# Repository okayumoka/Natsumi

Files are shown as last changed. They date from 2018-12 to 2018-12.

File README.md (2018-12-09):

# Natsumi

Natsumiは、コンパクトな左右分割型の自作キーボードです。

## 特徴

- 左右分離型
- キー数は両手で52キーと比較的少なく、コンパクト
- 手の形に合わせて山なりに配置したキー配列
- ケーブル類はすべて上部から接続

## 準備物

このリポジトリの内容物に加えて、以下のものが必要です。

### 部品

* ProMicroまたはその互換品×2
* ダイオード（1N4148または1SS178）
* Cherry MXキースイッチ、またはその互換スイッチ
* キーキャップ
* 配線用ケーブル
* [3.5mm 4極ミニジャック 基板取付用 MJ-4PP-9](http://akizukidenshi.com/catalog/g/gC-06070/)（秋月電子で購入可能）
* 3.5mm ステレオミニケーブル
* M3ネジ 長さ8mm ×8本（ケースのフタ固定用）
* M3ネジ 長さ5mm ×2本（ProMicro固定用）

Arduino Microは左右に一つずつ、合計2台必要です。
ダイオード、キースイッチ、キーキャップはキーの数だけ必要です。

### 工具・その他

* 半田ごて、半田
* ヤスリ、カッター（筐体の微調整用）
* グルーガン（ホットボンド）
* 3Dプリンター（なくてもOK）

ケースを印刷するために3Dプリンターを利用しますが、
無い場合は[DMM.make](https://make.dmm.com/print/)などの3Dプリントサービスを利用したので問題ありません。
むしろ多くの場合は、3Dプリントサービスに発注したほうが精度の高いケースを入手できます。

### 入手先

部品、工具の入手先の一例です。

* [TALP KEYBOARD](https://talpkeyboard.stores.jp/)
  * ProMicro互換機、ダイオード、キースイッチ、キーキャップとすべて揃います。
  * AliExpressと比べるとさすがに高いですが、すぐ発送してくれる・国内配送なので安心感があります。
* [AliExpress](https://www.aliexpress.com/)
  * ダイオード以外をAliExpressで買うと一番安く収まると思います。
* [秋月電子](http://akizukidenshi.com/catalog/default.aspx)
  * ダイオード、半田付けの道具、配線用ケーブルなどが購入できます。
  * 3.5mm 4極ミニジャック 基板取付用 MJ-4PP-9 はここで購入できます。
  * 安く揃えるなら以下がおすすめです。
    * 高速スイッチング・ダイオード　１ＳＳ１７８（１００本入）
    * 半田ごて：ニクロムはんだこて　ＫＳ－３０Ｒ（３０Ｗ）
    * 半田：はんだ　０．８ｍｍ SD-62
    * こて台：はんだこて台　ＳＴ－１１
    * ケーブル：スズメッキ線0.6mm、耐熱電子ワイヤー2m×7色
* [Amazon](https://www.amazon.co.jp/)
  * キーキャップ、半田付けの道具などが購入できます。
  * RepRap Prusa i3など、自分で組み立てるタイプの3Dプリンターも比較的安く手に入ります。

### 1.ケースの作成

`case` 以下の3Dモデルがケースとなっています。
3Dプリンターか、3Dプリントサービスを利用して出力します。

自前の3Dプリンターで印刷する場合、素材はPLAがおすすめです。
キーボード筐体は平たく、薄いため、熱収縮の大きいABSで反らないように印刷することは難しいでしょう。

### 2.キースイッチはめ込み

筐体の穴にCherry MXキースイッチをはめ込みます。

3Dプリンターの精度によっては穴のサイズがまちまちなので、ヤスリとカッターで調整します。
削りすぎないように注意してください。

キーキャップを交換するときなどにキースイッチが抜けてしまうのが嫌な場合は、
グルーガンでケースと固定してしまうとよいでしょう。

### 3.ミニジャック固定

3.5mm 4極ミニジャックを筐体に固定します。穴サイズが小さい場合はヤスリで調整します。
固定はグルーガンがおすすめです。

### 4.配線（半田付け）

配線図(`wiring`以下のファイル参照)通りに配線していきます。
ダイオードの向きに注意してください。
キースイッチから伸びている先の数字は、ProMicroのピン番号です。

配線図は、スイッチを筐体にはめ込んで裏返した状態となっています。
表から見た状態ではないので注意してください。

また、ProMicroの互換品はMicro USBジャックが折れやすいものが多いので、グルーガンで補強すると良いでしょう。
ただし、コネクタ内部にグルーガンのボンドが入らないように注意してください。

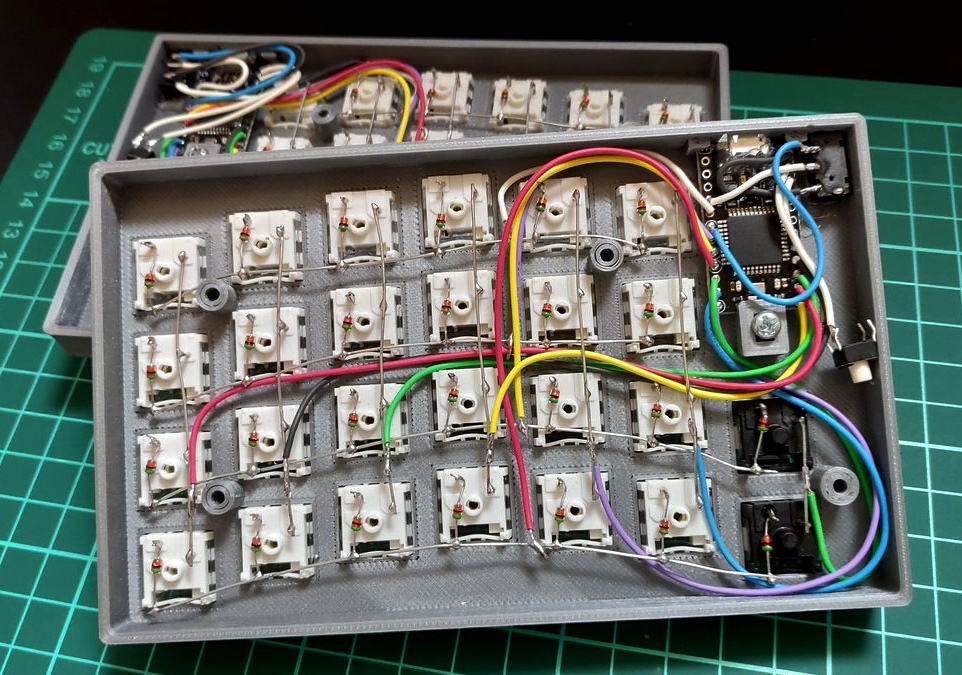
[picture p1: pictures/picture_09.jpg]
配線した状態


### 5.ファームウェア書き込み

ProMicroにQMK Firmwareを書き込みます。
QMK Firmwareのビルド環境を構築した後、`make natsumi:default:avrdude`を実行してください。

(2018/10/14) QMK Firmwareの公式リポジトリにはNatsumi用のファイルが存在していないため、
[こちらのリポジトリ](https://github.com/okayumoka/qmk_firmware)を`git clone`して使用してください。

### 6.ProMicro固定、裏蓋装着

ProMicro固定用の部品とネジで固定します。
グラつくときは、固定用部品をグルーガンで接着してください。

その後、裏蓋をネジ止めします。

### 7.キーキャップはめ込み

お好みのキーキャップを取り付けて、完成です。

## License

MIT License

Copyright (c) 2018 okayu

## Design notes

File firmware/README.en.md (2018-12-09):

# About Firmware

Natsumi work with [QMK Firmware](https://github.com/qmk/qmk_firmware).

# How to build

Setup QMK Firmware, and execute this command.

(2018/10/13) There is no Natsumi's sources in original QMK Firmware repository.
So, please use [this repository](https://github.com/okayumoka/qmk_firmware) files.
QMK Firmwareの公式リポジトリにはNatsumi用のファイルが存在していないため、

```
$ make natsumi:default:avrdude
```

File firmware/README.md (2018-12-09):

# ファームウェアについて

Natsumiは、[QMK Firmware](https://github.com/qmk/qmk_firmware)で動作します。

# ProMicroへの焼き込み手順

QMK Firmwareをビルドできる環境を整えてください。（ネット上にいろんな記事があるはずです。）

2018/10/13 QMK Firmwareの公式リポジトリにはNatsumi用のファイルが存在していないため、
[こちらのリポジトリ](https://github.com/okayumoka/qmk_firmware)を`git clone`して使用してください。

QMK Firmwareのディレクトリで、次のコマンドを実行してください。

```
$ make natsumi:default:avrdude
```

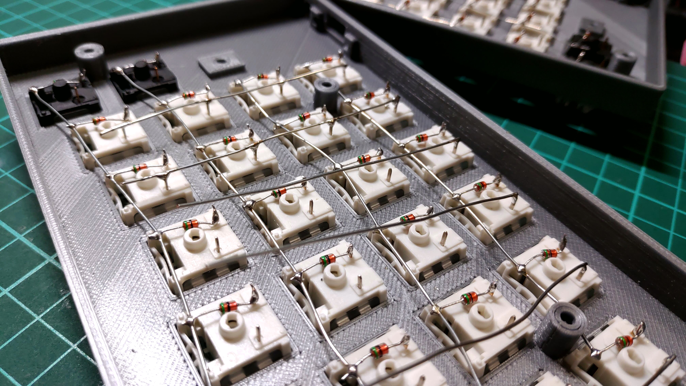
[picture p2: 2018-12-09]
pictures/picture_07.jpg

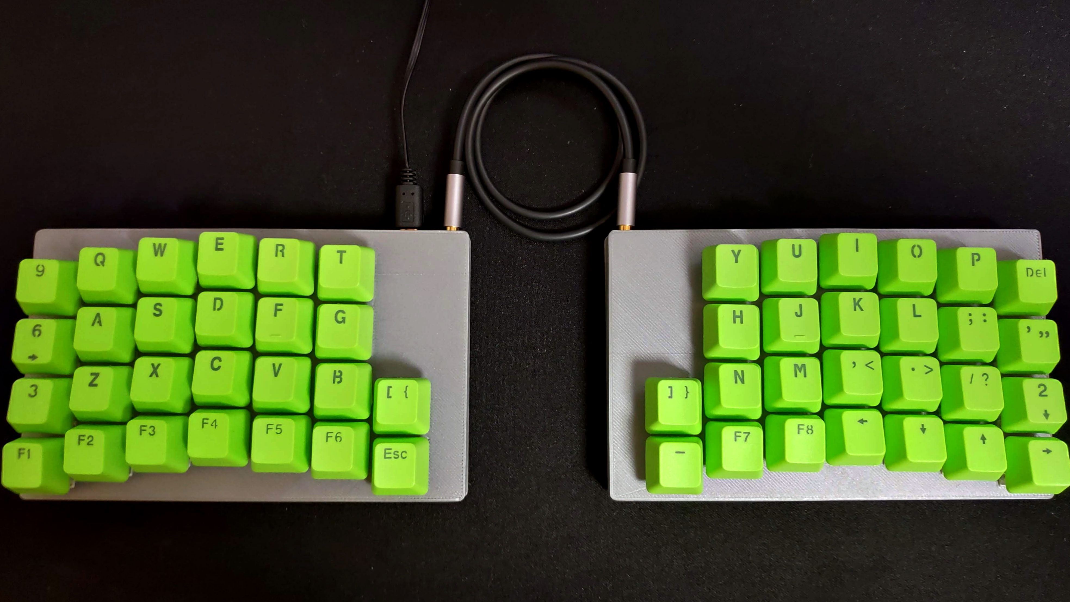
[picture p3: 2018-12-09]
pictures/picture_01.jpg

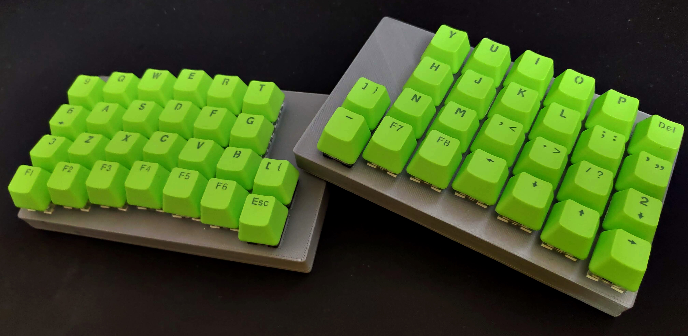
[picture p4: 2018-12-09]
pictures/picture_02.jpg

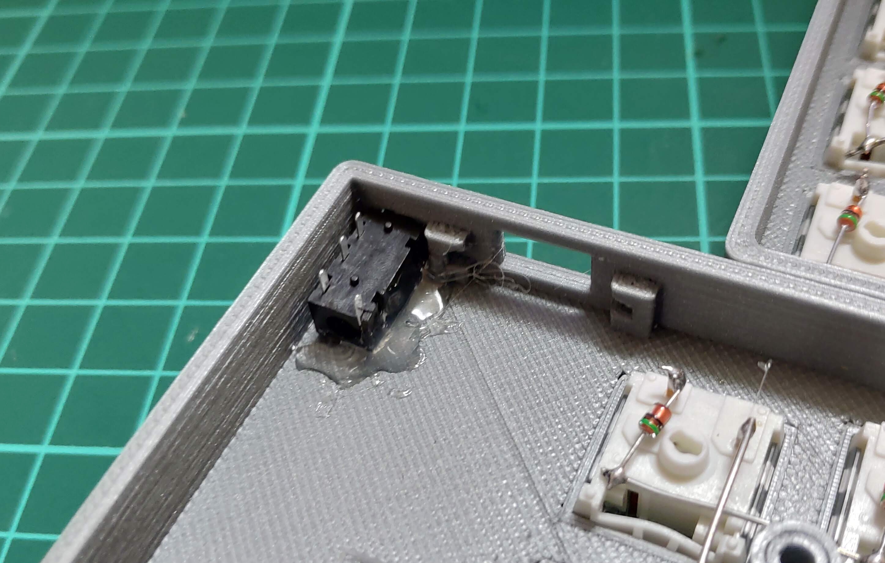
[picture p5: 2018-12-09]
pictures/picture_08.jpg

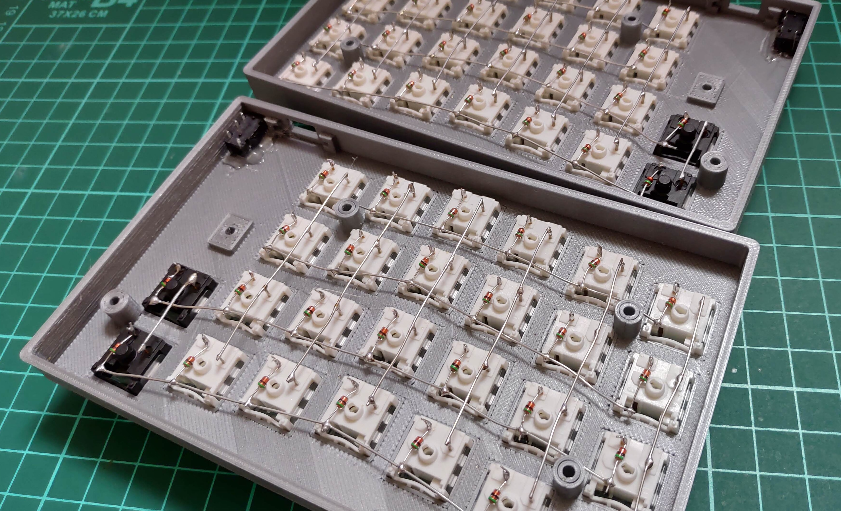
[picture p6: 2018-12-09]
pictures/picture_06.jpg

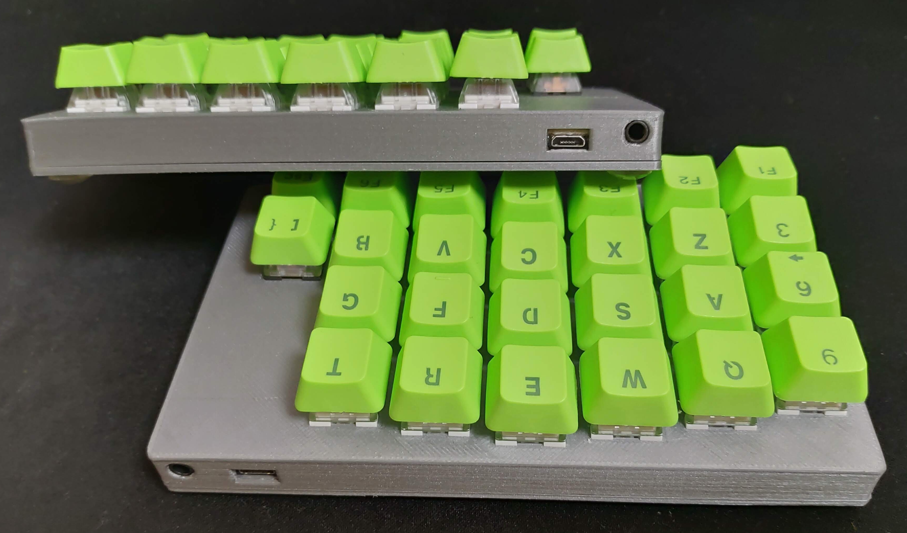
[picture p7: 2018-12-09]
pictures/picture_04.jpg

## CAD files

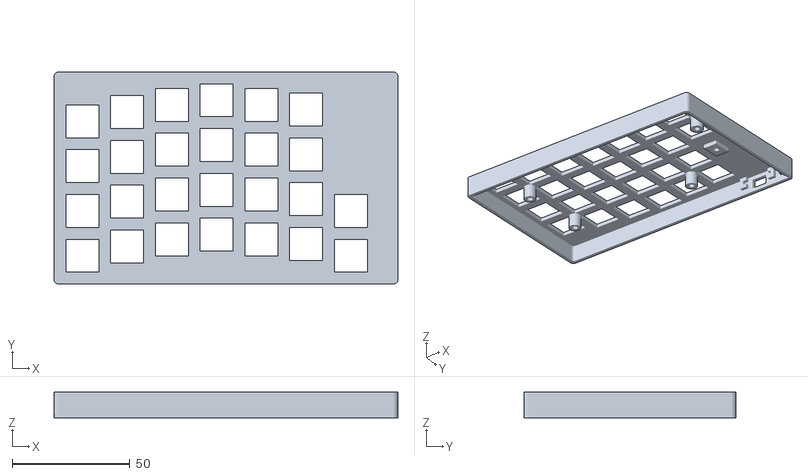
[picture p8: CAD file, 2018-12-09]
case/Top_L.stl
146.0 x 90.0 x 11.0

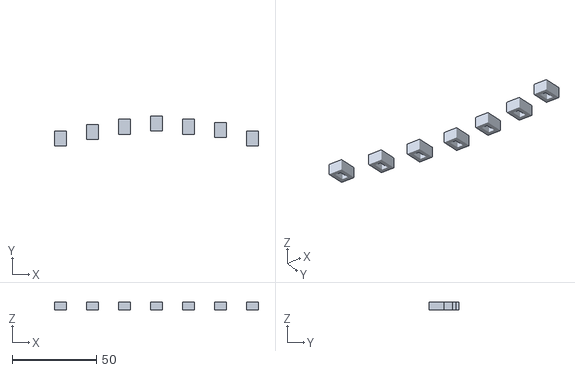
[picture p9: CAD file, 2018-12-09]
case/Jig.stl
121.0 x 18.0 x 5.00

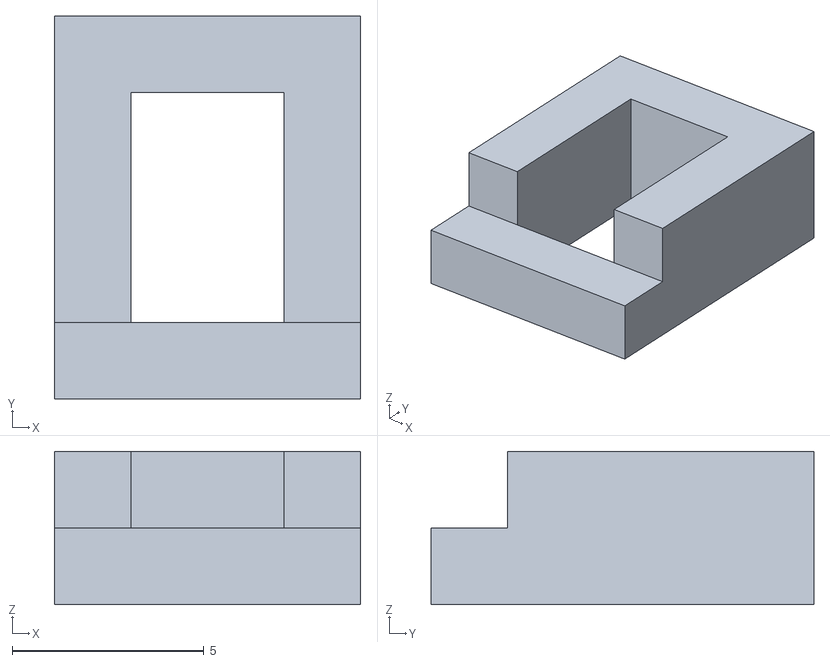
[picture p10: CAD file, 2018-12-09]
case/ProMicroStopper.stl
8.00 x 10.00 x 4.00

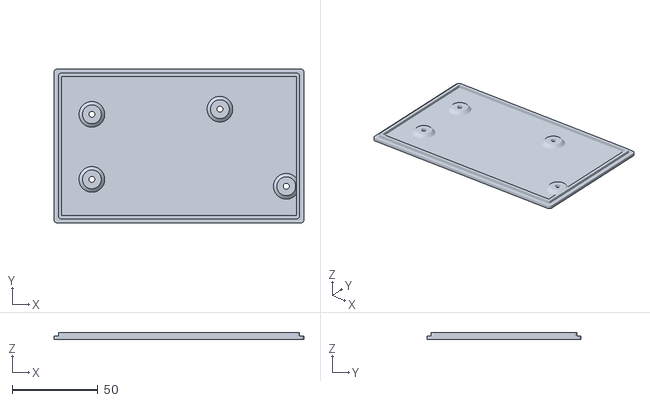
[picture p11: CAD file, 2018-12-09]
case/Bottom_L.stl
146.0 x 90.0 x 4.00

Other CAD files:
case/Top_R.stl
case/Bottom_R.stl

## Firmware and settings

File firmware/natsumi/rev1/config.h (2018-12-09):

/*
Copyright 2012 Jun Wako <wakojun@gmail.com>
Copyright 2015 Jack Humbert

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
You should have received a copy of the GNU General Public License
along with this program.  If not, see <http://www.gnu.org/licenses/>.
*/

#ifndef REV1_CONFIG_H
#define REV1_CONFIG_H

#include "config_common.h"

/* USB Device descriptor parameter */
#define VENDOR_ID       0xFEED
#define PRODUCT_ID      0x7770
#define DEVICE_VER      0x0001
#define MANUFACTURER    okayu
#define PRODUCT         natsumi v1
#define DESCRIPTION     A split keyboard for me

/* key matrix size */
// Rows are doubled-up
#define MATRIX_ROWS 8
#define MATRIX_COLS 7

// wiring of each half
#define MATRIX_ROW_PINS { D1, D4, C6, D7 }
#define MATRIX_COL_PINS { E6, B4, B5, B6, B3, B1, B2 }

/* define if matrix has ghost */
//#define MATRIX_HAS_GHOST

/* number of backlight levels */
// #define BACKLIGHT_LEVELS 3

/* Set 0 if debouncing isn't needed */
#define DEBOUNCING_DELAY 5

/* Mechanical locking support. Use KC_LCAP, KC_LNUM or KC_LSCR instead in keymap */
#define LOCKING_SUPPORT_ENABLE
/* Locking resynchronize hack */
#define LOCKING_RESYNC_ENABLE

/* key combination for command */
#define IS_COMMAND() ( \
    keyboard_report->mods == (MOD_BIT(KC_LSHIFT) | MOD_BIT(KC_RSHIFT)) \
)

/* ws2812 RGB LED */
#define RGB_DI_PIN D3
#define RGBLIGHT_TIMER
#define RGBLED_NUM 16    // Number of LEDs
#define ws2812_PORTREG  PORTD
#define ws2812_DDRREG   DDRD

/*
 * Feature disable options
 *  These options are also useful to firmware size reduction.
 */

/* disable debug print */
// #define NO_DEBUG

/* disable print */
// #define NO_PRINT

/* disable action features */
//#define NO_ACTION_LAYER
//#define NO_ACTION_TAPPING
//#define NO_ACTION_ONESHOT
//#define NO_ACTION_MACRO
//#define NO_ACTION_FUNCTION

#endif

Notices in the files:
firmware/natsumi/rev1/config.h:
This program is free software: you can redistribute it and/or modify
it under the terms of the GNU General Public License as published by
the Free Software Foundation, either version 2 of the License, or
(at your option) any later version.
